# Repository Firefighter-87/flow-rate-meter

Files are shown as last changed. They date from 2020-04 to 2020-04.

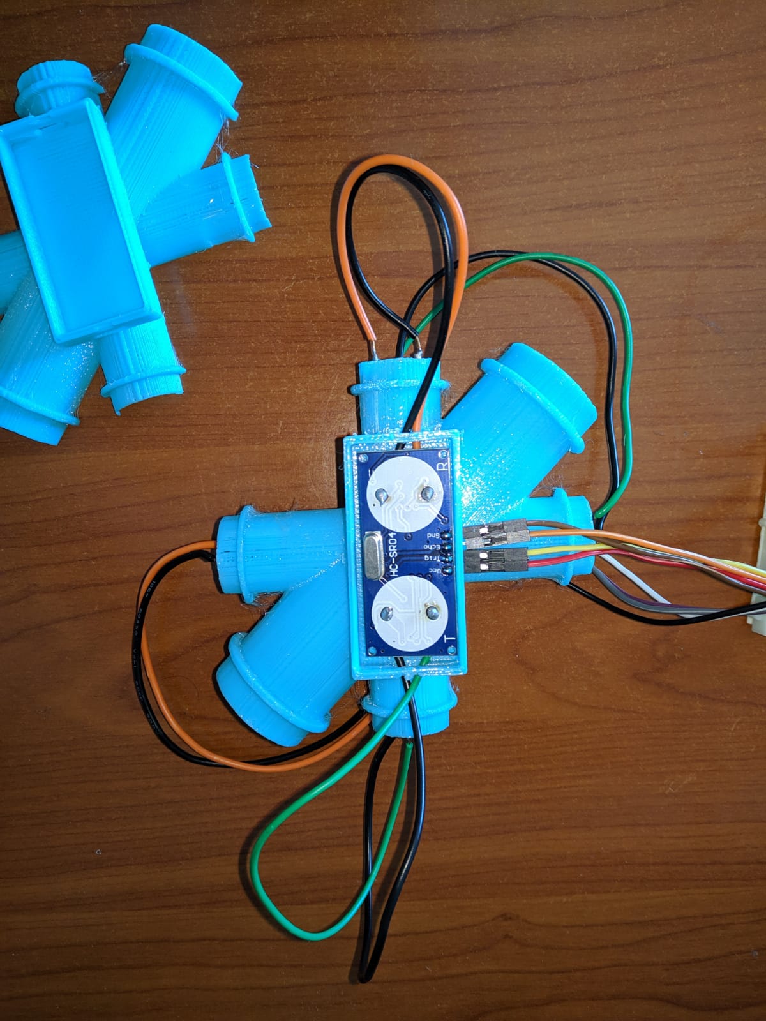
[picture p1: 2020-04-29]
Pictures/enclosure_etc (3).jpeg

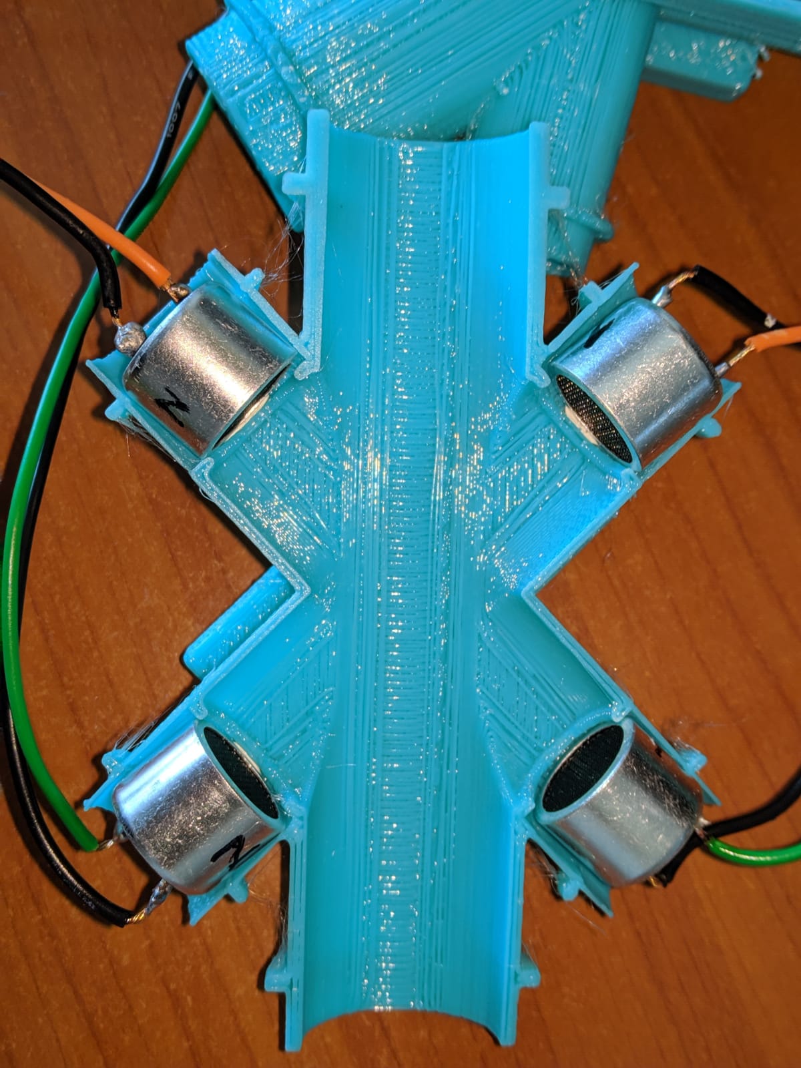
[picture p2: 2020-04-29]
Pictures/enclosure_etc (1).jpeg

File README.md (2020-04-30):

# flow-rate-meter
An ultrasound sensor to measure flow speed, rate and thrust based on the hobbyist module HC-SR04 and Arduino.

Measuring the flow of a gas at a low rate is not an easy task and sensors used for liquids are not a viable way, because the impeller inertia and the resistence it adds are no longer negligible. Professional sensors for this purpose beam the gas flow with an ultrasound wave and measure variations in travel times. I just have been wondering if i could apply this principle to a system based on hobbyist sensors (HC-SR04).

The pivotal idea of an ultrasonic flowrate meter is to use two sets of transmitter-receiver modules to generate a wave and measure its speed with and against the air flow, being the flow speed the average of them. The two trains of wave would be intermitting and alternate not to interfere with one another. This kind of calculus allows me to do without the speed of sound, because it depends on the pressure of the gas which is variable over time.

As for now, I'm stuck in a point where the device has low sensibility and might false reading. I think sensibility can be improved by replacing crystal from 40hz to say 100hz or higher. As for false readings, I think it may depend on digitalRead function which sometimes might read floating pins (I've to check wether the issue can be overturn with pull-up or pull-down resistors as explained here: https://forum.arduino.cc/index.php?topic=55119.0 or can be fixed by software as explained here: https://forum.arduino.cc/index.php?topic=573246.0). For, I think that the project is at a stage advanced enought to be shared. Tips for fixing issues and improving its design or functioning are all welcome.

As for housing, the main body might result in a nightmare to 3D print if you are not experienced enough. I'm providing three verions of it. The threaded one is fine if you have a SLA 3d printer. The nonthreaded version is for those with FDM printers. Alternatively, you can print the half version twice and seam the two halves with hot glue (which is also needed to seal the device). In any case you'll need to enable supports in your slicer. CAD files are also included in case you need to adjust tolerances.

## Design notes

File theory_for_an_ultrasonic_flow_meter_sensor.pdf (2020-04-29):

Calculations for an ultrasound flow rate sensor

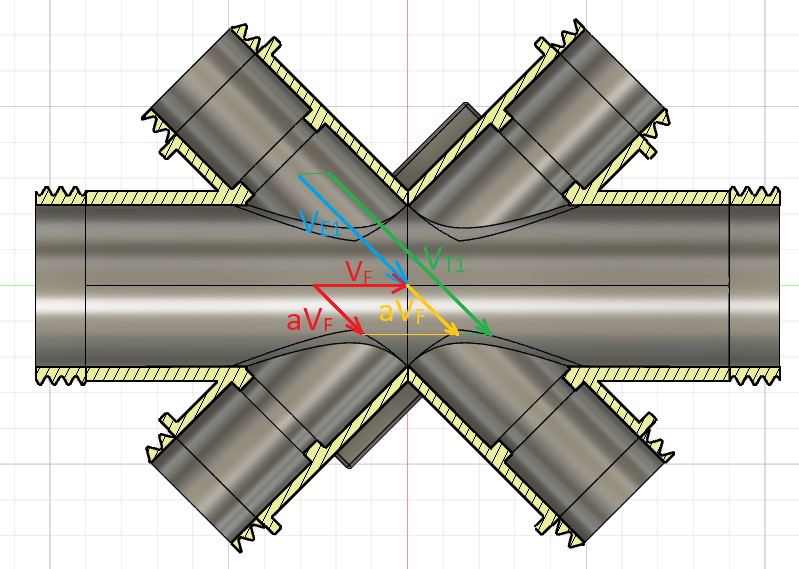
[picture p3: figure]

Syllabus

VT1: | Final velocity of tone 1
VT2: | Final velocity of tone 2
VS1: | Source velocity of tone 1
VS2: | Source velocity of tone 2

VE1 e VE2 depend on the pressure within the flow but they will disappear over calculus, thus we don’t really need to know their actual value.

VF

: | Air flow velocity
t1: | Travel time of tone 1
t2: | Travel time of tone 2
L: | transmitter-receiver distance (inferred from t1 or t2 measured in quiet state)

Calculus

V = V + aV | (1)
V = V − aV | (2)

Since the air blows onto the acoustic wave from a flank, with an angle (α), both VE1 and VE2 will be increased by a component of VF

, aVF

, named this way because its magnitude is a percentage (a) of VF

. The difference
between the higher magnitude (VT1) and the lower (VT2) is almost twice aVF

. And since sensors actually allow us measure these values, the difference can be calculated easily. From what was said here, and considering we are interested in the difference as an absolute value without sign, you extrapolate that:

aV =

(3)

So far, (a) has been referred to as a generic percentage. But in order for the calculus to go on, you’ve to find out its content and write it explicitly. If we were given the number (x) and were we said that it is the value of aVF and were the angle (α) 45 deg, finding the whole VF would only require the trigonometric rule to switch from the side to the diagonal of a square, that is multiplying x by √2. We would have the following situation:

V = √2 ∙ x | (4)
V = √2 ∙ aV | (5)

Instinctively, we would realize that in order for proposition (5) to be true, √2 ∙ a must return 1 and therefore a = 1/√2. But 1/√2 is sin(45°) or cos(45°), that is the sine or the cosine of our angle. For, we choose a = cos(α).

Going back to proposition (3) and replacing with the result we found and showing (L)s and (t)s contained in (VT)s, this is what we find:

cos (α) ∙ V =

|V − V| | (6)

cos (α) ∙ V =

−

| (7)

V =

()

L

−

| (8)

V =

()

∙

| ∙ | (9)

Now the trouble is that, in the real world, L measures the distance between transmitter and receiver, which changes slightly in each couple, no matters how much effort we make to keep it the same everywhere. Nor can we consider an average value of it (what would produce great inaccuracy). We are compelled to consider both distances individually. For, let’s discard the generic relation (9), go back to step (7) and let’s solve for the real world:

cos (α) ∙ V =

−

| (7a)

V =

()

−

| (8a)

V =

()

∙

| ∙ | (9a)

Flow is meant here as the volume of air passing across a section of pipe over the time unit. To reckon it, you also need to measure the surface (S) of the opening of the air pipe and multiply it by the distance (d) that the air covers over the time unit. If time units are seconds, we’ll have:

d(m) = V

(m/s) ∙ 1(s) = V(m)

Ḟm3/s =

S(m
) ∙ V(m)
1(s)

= S ∙ VFm3/s

That we can turn into either L/m or dm³
/s through the proper equivalence.

If we also know the density (ρ) of the gas, we can reckon the thrust of the air flow. To begin you need to estimate the flow rate (the mass in grams of the air flowing through the section over the time unit):

Ṙ(g) = Ḟ(m/s) ∙ ρ(kg/m )

The result you need to multiply by velocity, because thrust, as a phisical dimension, isn’t other but momentum (quantity of motion) Q = m∙v. Our mass (m) is the flow rate (R), while our velocity keeps being (VF):

Q

kg ∙ m
s

= Ḟ(m/s) ∙ ρ(kg/m
) ∙ V

(m/s)

Q(N) = S ∙ VF

2

- ρ

kg ∙ m
s

2

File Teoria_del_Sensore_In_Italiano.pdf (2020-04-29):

Calcoli per un sensore di flusso a ultrasuoni


Syllabus

VT1: | Velocità finale del tono 1
VT2: | Velocità finale del tono 2
VS1: | Velocità del tono 1 alla sorgente
VS2: | Velocità del tono 2 alla sorgente

VE1 e VE2 dipendono dalla pressione all’interno del flusso ma scompaiono nei calcoli, così non abbiamo bisogno di conoscere il loro effettivo valore.

VF

: | Velocità del flusso d’aria
t1: | Tempo di percorrenza del tono 1
t2: | Tempo di percorrenza del tono 2
L: | Distanza ricevente-trasmittente (dedotta da t1 o t2 misurati in stato di quiete)

Calculus

V = V + aV | (1)
V = V − aV | (2)

Poiché l’aria soffia sull’onda acustica lateralmente, con un angolo (α), VE1 e VE2 saranno incrementate o decrementate con una componente di VF

: aVF

così indicata perché il suo modulo è una percentuale (a) di VF

. La
differenza tra il maggiore dei due moduli (VT1) e il minore (VT2) è circa 2 volte aVF

. E poiché i sensori ci
permettono di misurare la velocità finale sia col vento a favore (VT1) e sia col vento a sfavore (VT2), possiamo sicuramente eseguire questo calcolo. Da quanto detto fin qui, e considerando che ci interessa la differenza di moduli in valore assoluto e senza segno, estrapoliamo che:

aV =

(3)

Finora, a è stata descritta come una generica percentuale. Ma per continuare i calcoli, dobbiamo scoprire cosa contiene e scriverlo esplicitamente. Se ci dessero un numero x e ci dicessero che esso è il valore di aVF e che l’angolo α è di 45°, per trovare tutto VF

applicheremmo le regole trigonometriche della diagonale del quadrato e moltiplicheremmo il nostro numero per √2. Avremmo cioè la seguente situazione:

V = √2 ∙ x | (4)
V = √2 ∙ aV | (5)

Istintivamente vedremmo che per essere vera la (5), √2 ∙ a deve fare 1 e quindi che a = 1/√2. Ma 1/√2 è il sen(45°) o il cos(45°), cioè il seno o coseno del nostro angolo. Per il nostro disegno possiamo scegliere indifferentemente uno dei due. Allora scegliamo a = cos(α).

Andando a sostituire nella 3 con il risultato trovato e con L e risolvendo per VF

, ecco cosa troviamo:

cos (α) ∙ V =

|V − V| | (6)

cos (α) ∙ V =

−

| (7)

V =

()

L

−

| (8)

V =

()

∙

| ∙ | (9)

Il problema è che nella realtà non esiste un solo L comune in tutte due le coppie trasmittente-ricevente. Per quanto ci sforziamo di essere precisi, avremo sempre un L1 e un L2 diversi tra loro e non possiamo considerare una loro media (produrrebbe grosse inesattezze). Siamo costretti a considerarli entrambi. Perciò scartiamo la
(9) (formula teorica) e torniamo nella (7) per ricavare una formula pratica:

cos (α) ∙ V =

−

| (7a)

V =

()

−

| (8a)

V =

()

∙

| ∙ | (9a)

Per flusso intendiamo il volume d’aria che attraversa una sezione di tubo nell’unità di tempo. Per determinare il flusso, bisogna calcolare anche la superficie (S) dell’apertura della condotta d’aria e moltiplicarla per la distanza
(d) che l’aria percorre nell’unità di tempo. Se l’unità di tempo è il secondo, abbiamo:
| d(m) = V

(m/s) ∙ 1(s) = V(m)

| Ḟm3/s =

S(m
) ∙ V(m)
1(s)

= S ∙ VFm3/s

Che possiamo trasformare in L/m o dm³ | /s con l’opportuna equivalenza.

Se conosciamo anche la densità ρ del gas, possiamo calcolare anche la spinta del getto d’aria. Si procede determinando innanzitutto la portata (massa d’aria fluita attraverso la sezione nell’unità di tempo):

| Ṙ(g) = Ḟ(m/s) ∙ ρ(kg/m
)

Il risultato va moltiplicato per la velocità, perché la spinta, come grandezza fisica, non è altro che la quantità di moto Q = m∙v. La nostra massa è la portata R, mentre la nostra velocità è sempre VF

:

Q

kg ∙ m
s

= Ḟ(m/s) ∙ ρ(g/m
) ∙ V

(m/s)

Q(N) = S ∙ VF

2

- ρ

kg∙m
s

2

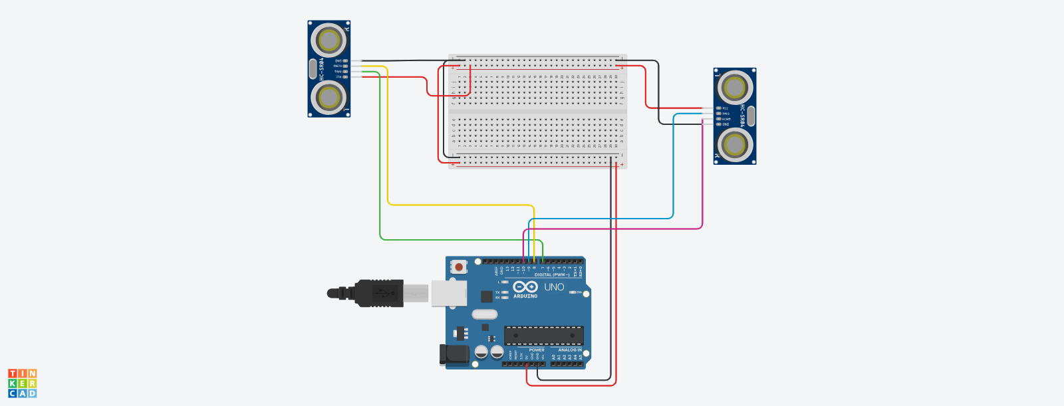
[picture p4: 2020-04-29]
Pictures/Flow-Sensor-schematics.png

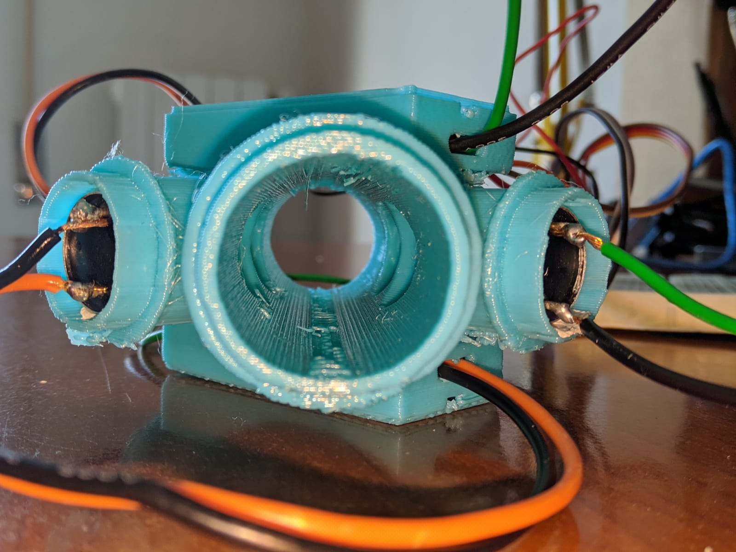
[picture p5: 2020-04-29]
Pictures/enclosure_etc (2).jpeg

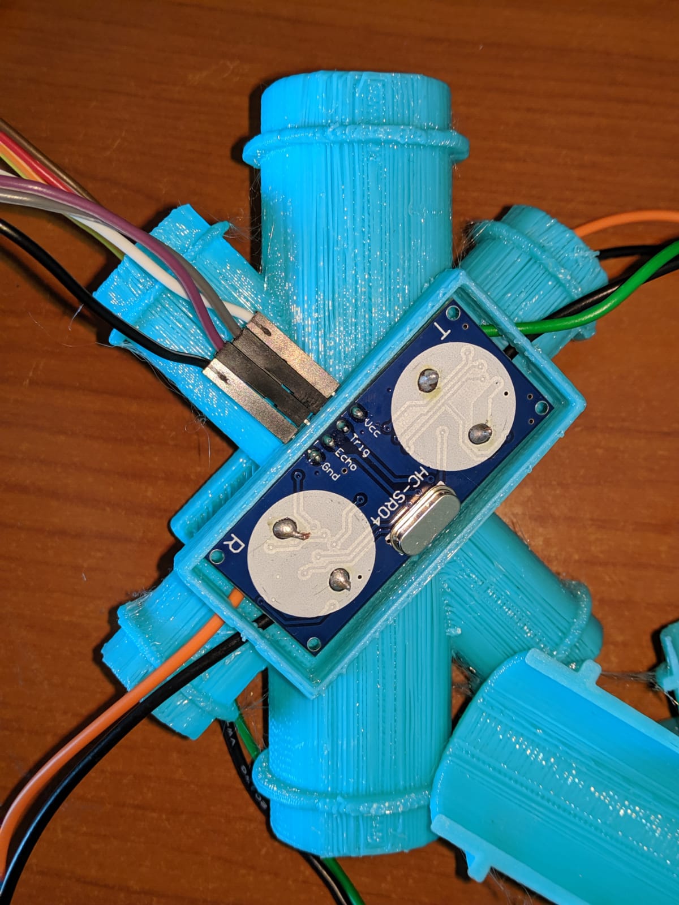
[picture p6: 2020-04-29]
Pictures/enclosure_etc (5).jpeg

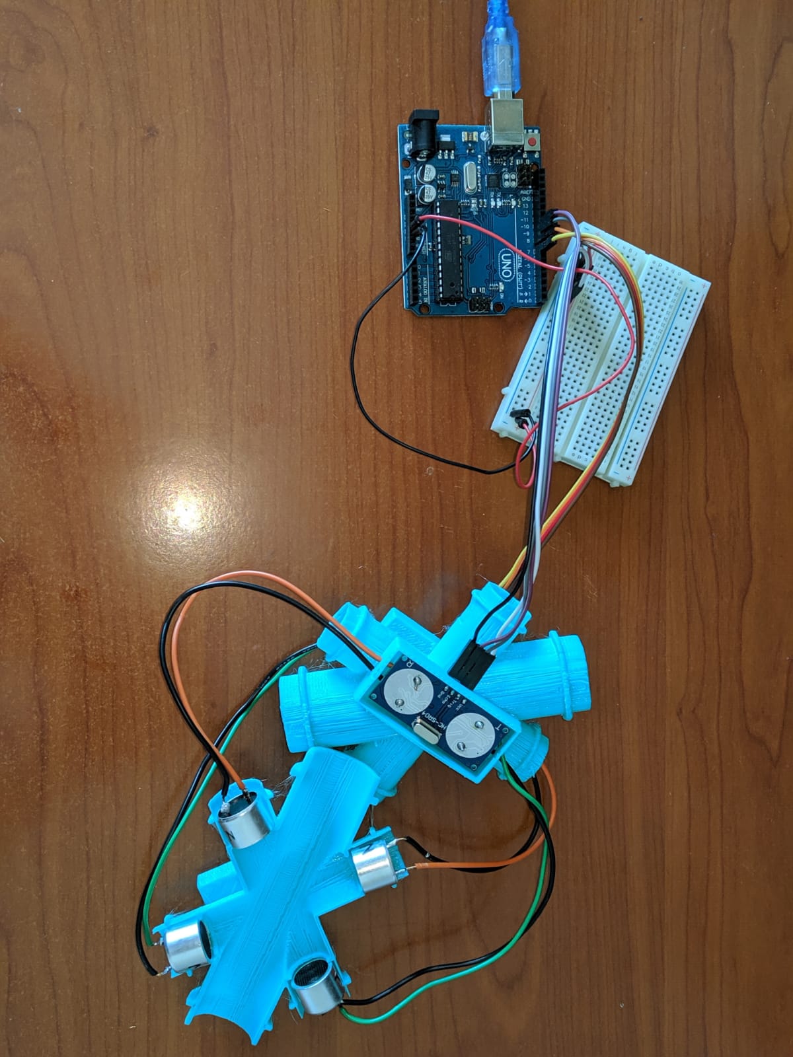
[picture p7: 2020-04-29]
Pictures/enclosure_etc (4).jpeg

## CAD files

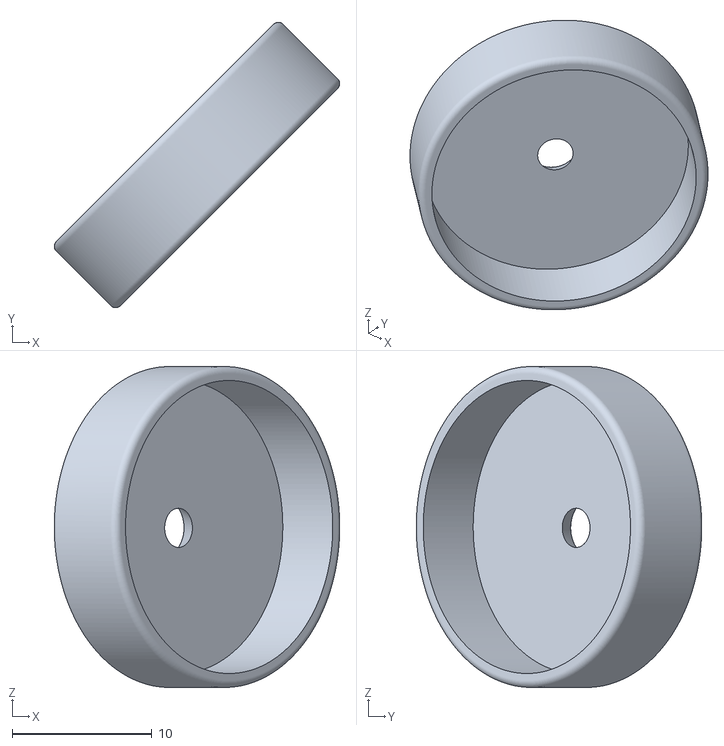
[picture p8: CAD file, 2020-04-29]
STL/Tappino_non_filettato.stl
20.4 x 20.4 x 22.9

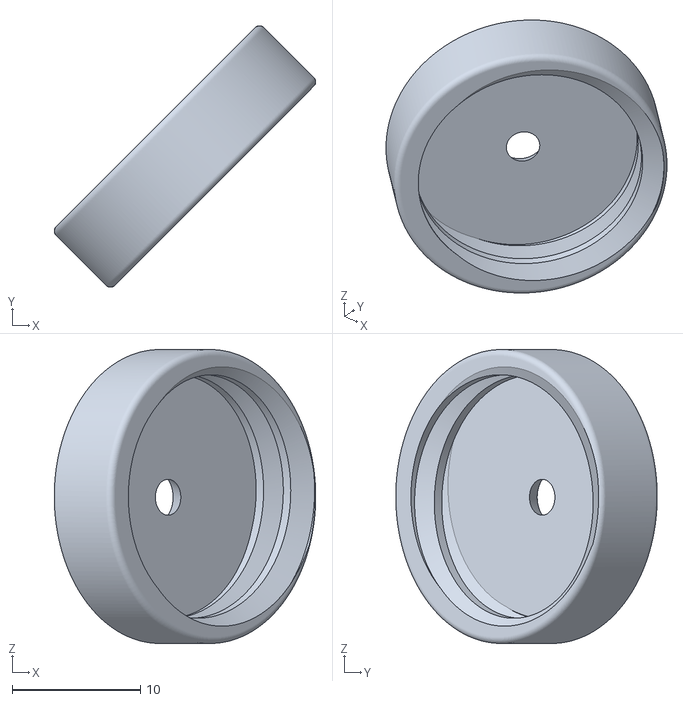
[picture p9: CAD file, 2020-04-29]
STL/Tappino.stl
20.4 x 20.4 x 22.9

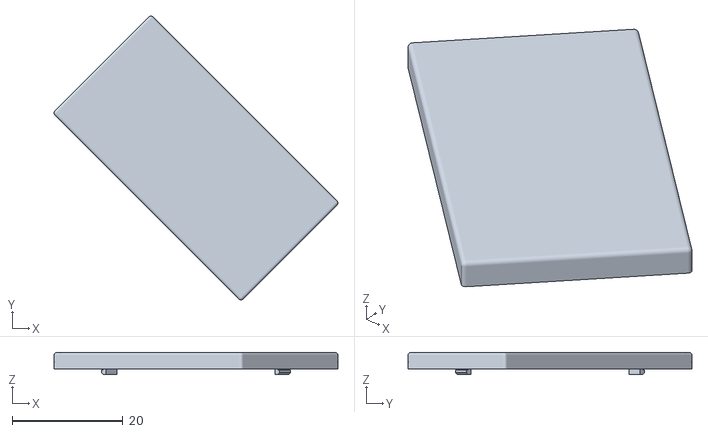
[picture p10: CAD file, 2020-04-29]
STL/Coperchio.stl
51.2 x 51.2 x 4.00

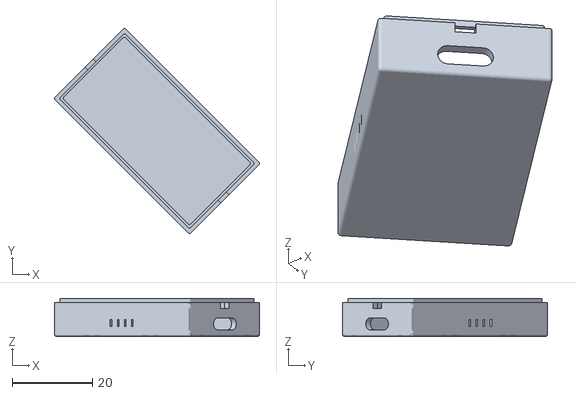
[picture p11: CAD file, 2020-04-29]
STL/Scatola.stl
51.2 x 51.2 x 9.50

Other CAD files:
CAD/Flow_Sensor_2 v12.f3z

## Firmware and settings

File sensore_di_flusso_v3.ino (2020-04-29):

//sensore di flusso aria con moduli ultrasuoni HC RS04
const int triggerPort1 = 7;
const int echoPort1 = 8;
const int triggerPort2 = 9;
const int echoPort2 = 10;
bool calibrato = false;
unsigned long t1, t2, d1, d2, D1T2, D2T1;
float angleDeg = 45;
float angleRad = (angleDeg * 71) / 4068.0;
const float coeffVel = (1/(2*cos(angleRad))); //parte costante della formula della velocità
const float ro = 1.184; //kg/m^3 a 20 gradi celsius
const float internalR = ((21+21.7)/2)/2; //valore medio misurato col calibro in mm
const float superficie = internalR*internalR*PI/1000000;//da mm^2 a m^2
float VF, spinta, flusso;
 
void setup() {
pinMode(triggerPort1, OUTPUT);
pinMode(echoPort1, INPUT);
pinMode(triggerPort2, OUTPUT);
pinMode(echoPort2, INPUT);
Serial.begin(9600);
Serial.println( "flusso istantaneo");
Serial.print("sezione condotta area in cm^2 :");
Serial.println(superficie*10000, 6); //trasformo in cm^2 e tengo 6 cifre significative
//Serial.print("sezione condotta area in m^2 :");
//Serial.println(superficie, 6); //trasformo in cm^2 e tengo 6 cifre significative
}

void loop() {
  if (!calibrato){
    Serial.println("calibrazione in corso, non soffiare nel tubo");
    //porta bassa l'uscita del trigger1
    digitalWrite( triggerPort1, LOW );
    //invia un impulso di 10microsec su trigger1
    digitalWrite( triggerPort1, HIGH );
    delayMicroseconds( 10 );
    digitalWrite( triggerPort1, LOW );
    t1 = pulseIn( echoPort1, HIGH ); //rilevo i microsecondi...
    digitalWrite( echoPort1, LOW );
    d1 = 346 * t1; //in micrometri (346 sono i metri percorsi dal suono in 1 secondo a 25°C; t1 è espresso in microsecondi). Dovremo poi dividere per 1.000.000 per passare da micrometri a metri nel risultato finale.
    // lo facciamo nel risultato finale per non perdere fin da ora cifre significative usando subito un float (che ha solo 7/8 cifre significative)
    
    delay(200);
    
    //porta bassa l'uscita del trigger2
    digitalWrite( triggerPort2, LOW );
    //invia un impulso di 10microsec su trigger1
    digitalWrite( triggerPort2, HIGH );
    delayMicroseconds( 10 );
    digitalWrite( triggerPort2, LOW );
    t2 = pulseIn( echoPort2, HIGH ); //rilevo i microsecondi...
    digitalWrite( echoPort2, LOW );
    d2 = 346 * t2; //anche qui dovremo dividere per 1.000.000 per passare da micrometri a metri nel risultato finale
    Serial.println("calibrazione terminata, adesso è possibile soffiare nel tubo");
    calibrato = true;
  }
//Serial.print("coeffVel: ");
//Serial.println(coeffVel);

//Serial.println(d1);
//Serial.println(d2);

//porta bassa l'uscita del trigger1
digitalWrite( triggerPort1, LOW );
//invia un impulso di 10microsec su trigger1
digitalWrite( triggerPort1, HIGH );
delayMicroseconds( 10 );
digitalWrite( triggerPort1, LOW );
t1 = pulseIn( echoPort1, HIGH ); //rilevo i microsecondi (anche qui dovremo dividere per 1.000.000 per passare da microsecondi a secondi nel risultato finale)
digitalWrite( echoPort1, LOW );
//Serial.print("t1: "); 
//Serial.println(t1); 

delay(150); //questo delay è necessario per assestare Arduino, prima di dare potenza all'altro sensore (non scendere al di sotto di 150)

//porta bassa l'uscita del trigger2
digitalWrite( triggerPort2, LOW );
//invia un impulso di 10microsec su trigger1
digitalWrite( triggerPort2, HIGH );
delayMicroseconds( 10 );
digitalWrite( triggerPort2, LOW );
t2 = pulseIn( echoPort2, HIGH ); //idem, dovrò poi ricordanrmi di andare a dividere per 1.000.000 per passare da microsecondi a secondi nel risultato finale
digitalWrite( echoPort2, LOW );
//Serial.print("t2: ");
//Serial.println(t2); 


D1T2 = d1*t2; //questo valore è in micrometri*microsecondi
//Serial.print("D1T2: "); 
//Serial.println(D1T2); 

D2T1 = d2*t1; //e così anche questo
//Serial.print("D2T1: "); 
//Serial.println(D2T1);

//calcolo grandezze
VF = coeffVel*(abs(D1T2-D2T1))/(t1*t2);
//questo valore è in micrometri/microsecondi.
//è arrivato il momento di dividere micrometri e microsecondi per 1.000.000. 
//Numericamente il risultato non cambia, perché equivale a moltiplicarlo per 1.000.000/1.000.000, ma l'unità di misura diventa finalmente m/s.
//Convertendo alla fine anziché all'inzizio abbiamo conservato il maggior numero possibile di cifre significative.

flusso = (VF*superficie)*60*1000; //in m^3/s a L/min
spinta = (superficie*VF*VF*ro); //N (or kg*m/s^s)

//velocità
Serial.println("");
Serial.print("velocità: ");
Serial.print(VF, 6); //tengo 6 cifre significative
Serial.println(" m/s");

//flusso
Serial.print("flusso: ");
Serial.print(flusso, 6); //tengo 6 cifre significative
Serial.print(" L/min o ");
Serial.print(flusso/60000, 12);
Serial.println(" ml/s");

//spinta (not really required for ventilation)
Serial.print("spinta: ");
Serial.print(spinta);
Serial.println(" N");


//Aspetta non scendere al di sotto di 150 microsecondi
delay(2000);
}

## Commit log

2020-04-29 Add files via upload
    Arduino code (Italian captions)
2020-04-29 Add files via upload
    STL files of the parts to 3D print
    [Coperchio.stl, Scatola.stl, Tappino.stl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]
2020-04-29 Add files via upload
    Working principle of this sensor.
    Principio di funzionamento di questo sensore.
2020-04-29 Add files via upload
    Cad archive (you need Fusion 360 to extract it)
    [Flow_Sensor_2 v12.f3z]
